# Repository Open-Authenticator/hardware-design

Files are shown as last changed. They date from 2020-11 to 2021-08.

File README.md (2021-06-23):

# Open Authenticator Hardware Design

This repository contains hardware design files and datasheets for the open authenticator. This project is in development and is not ready for release.



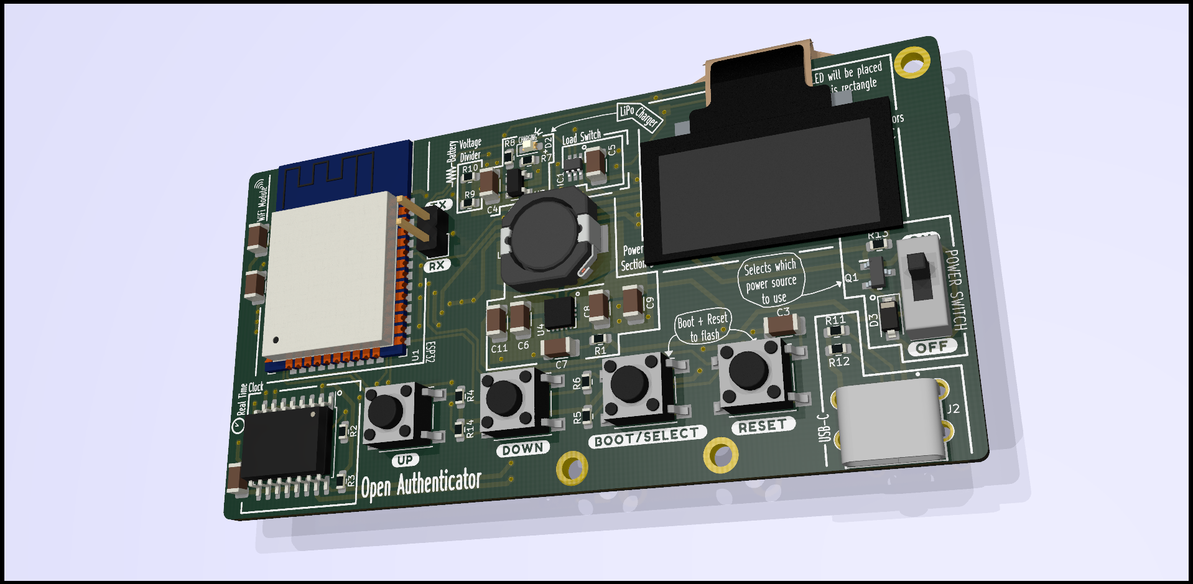
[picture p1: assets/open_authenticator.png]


## Features

* Small form factor of 82mm x 42mm
* Uses ESP32-WROOM-32D module
* Uses 128x64 0.96" inch OLED panel
* Uses DS3231 RTC with battery backup (CR2032) for timekeeping
* Powered by 3.7V 300 mAh LiPo battery
* Uses MCP73831 for charging LiPo battery
* Uses TPS63001 Buck Boost Converter IC for efficient 3.3V power supply, with input range from 1.8V - 5.5V
* Uses TPS22919 Load switch to control power to OLED and RTC chip
* Autoselect power source, i.e., battery or USB
* USB Type-C for charging only (no data pins connected)

## Project Structure

```
/datasheets - contains datasheets of various components used in the pcb
/kicad_project - contains kicad project files for the pcb
/schematics - contains schematics of the the pcb
```

## Tools

To view/modify the files from this repository, install KiCAD from: [https://kicad.org](https://kicad.org)

## Schematics



## Plots

### Front side

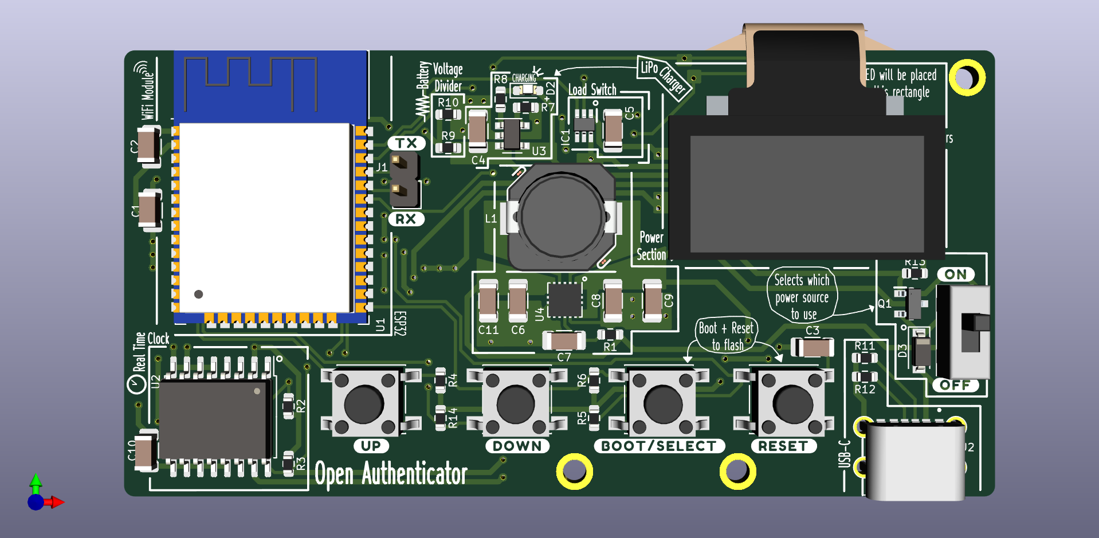
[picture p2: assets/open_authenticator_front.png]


### Back side

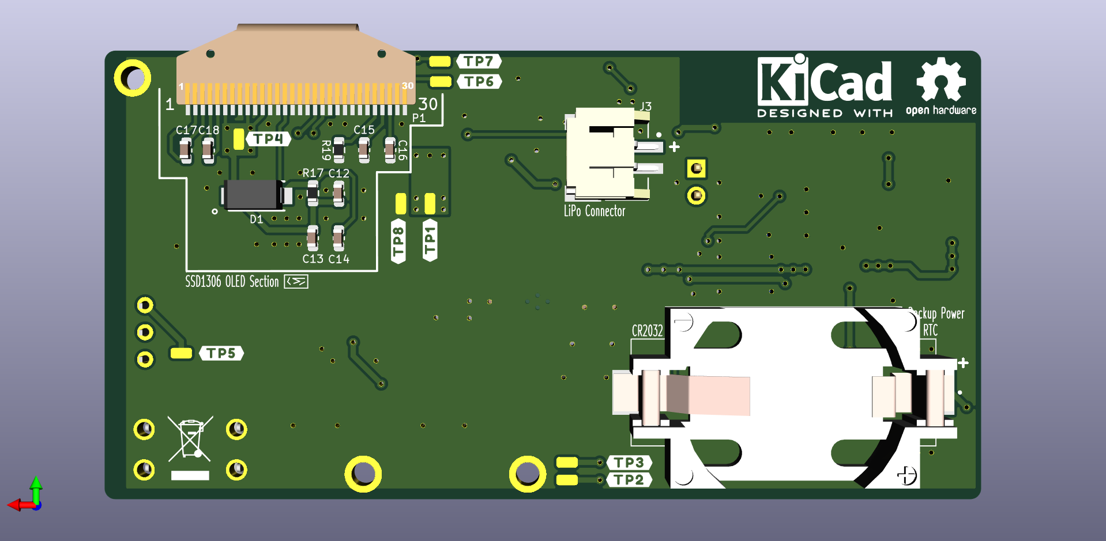
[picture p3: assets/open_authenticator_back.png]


## Credits



Thanks to OSHPark for sponsoring first prototypes



Thanks to PCBway for sponsoring the final prototypes

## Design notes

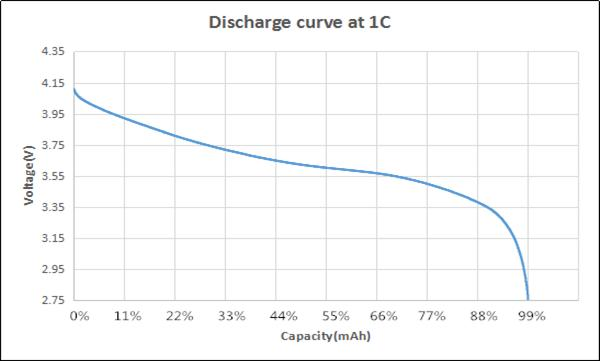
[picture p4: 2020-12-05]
datasheets/battery_discharge_curve.png

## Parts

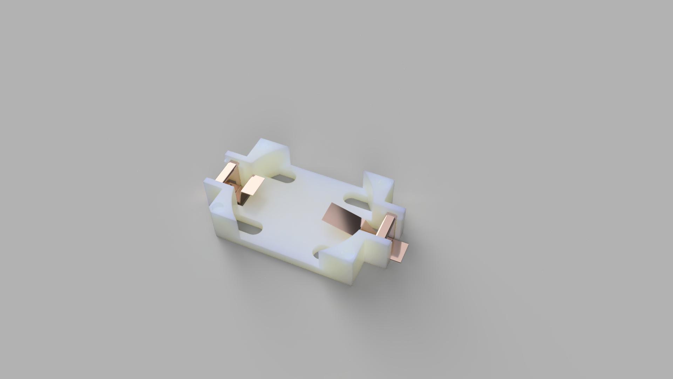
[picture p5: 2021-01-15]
kicad_project/component_libraries/2032-BS-6-1-coin-cell-holder/CR2032_holder_2018-Jul-28_07-22-14PM-000_CustomizedView1611227186.jpg

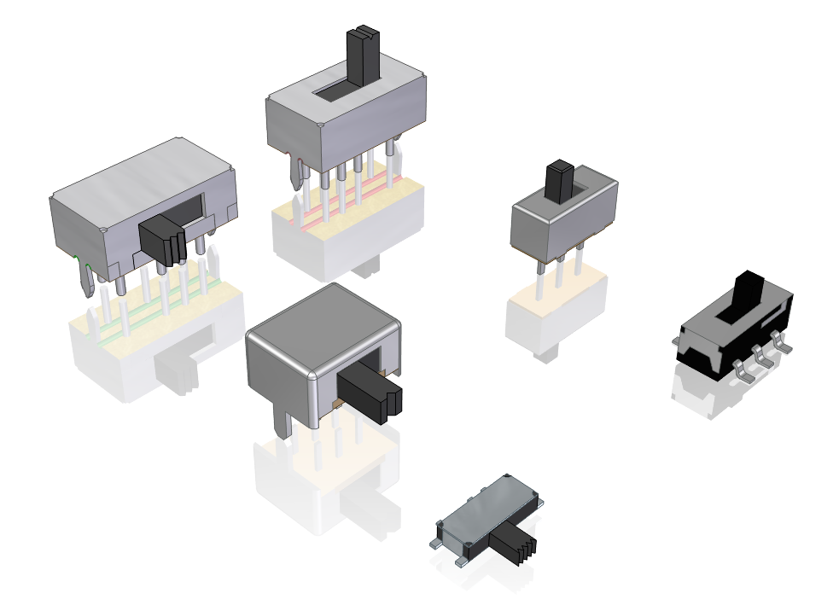
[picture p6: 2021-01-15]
kicad_project/component_libraries/SS-12D00-slide-switch/Selector Switch Assortment.PNG

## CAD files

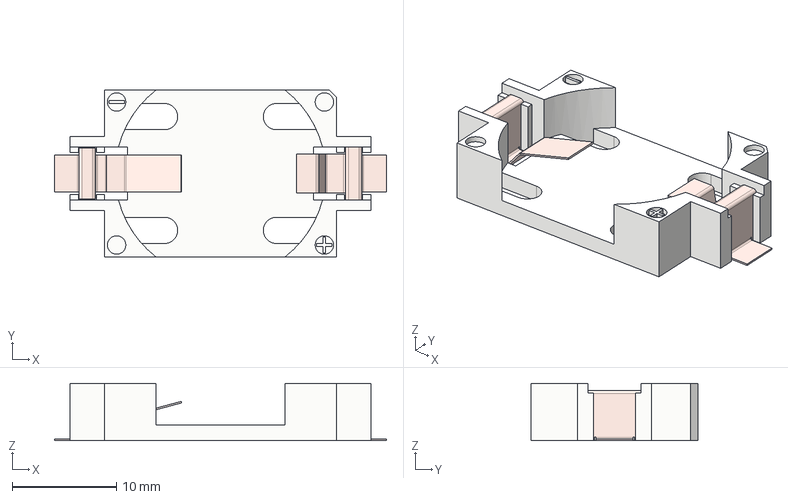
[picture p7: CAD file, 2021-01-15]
kicad_project/component_libraries/2032-BS-6-1-coin-cell-holder/CR2032 holder.step
31.8 x 16.0 x 5.50 mm
base
connector_plus
connector_minus

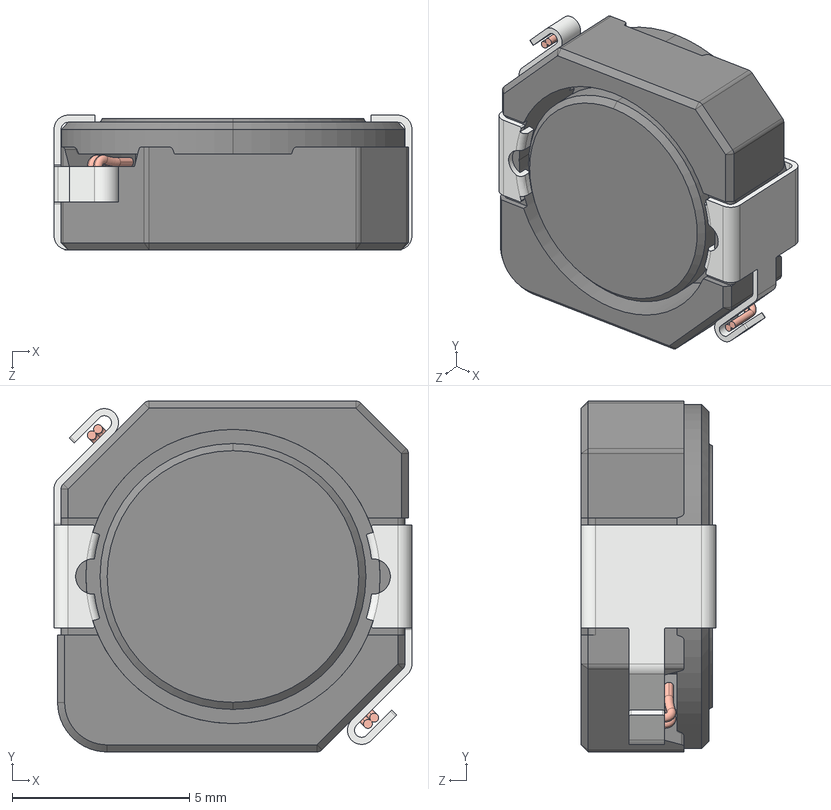
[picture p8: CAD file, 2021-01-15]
kicad_project/component_libraries/CDRH104RNP-inductor/CDRH104R.STEP
10.1 x 9.90 x 3.80 mm

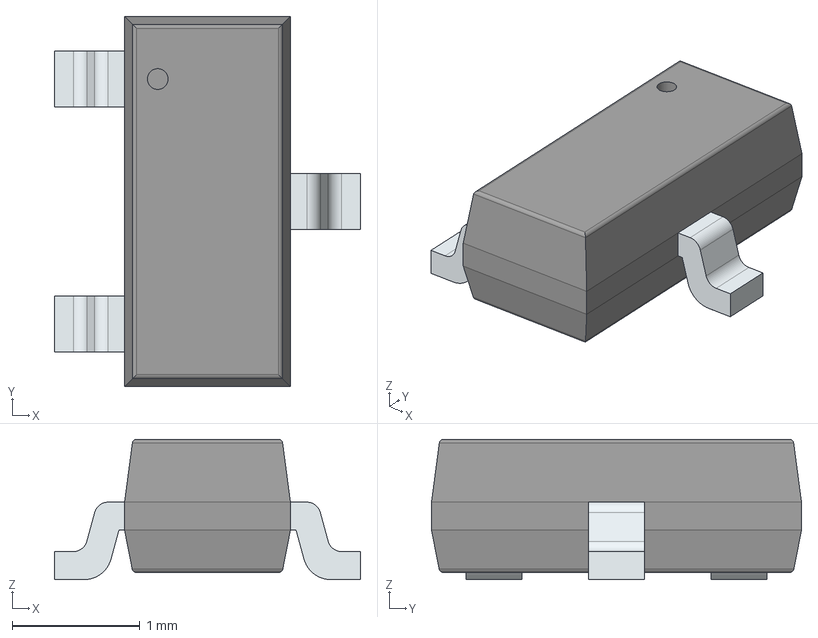
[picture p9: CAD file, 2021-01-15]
kicad_project/component_libraries/DMP2305U-mosfet/DMP2305U-7.stp
2.40 x 2.90 x 1.10 mm
PinsArrayL
FilletPinR

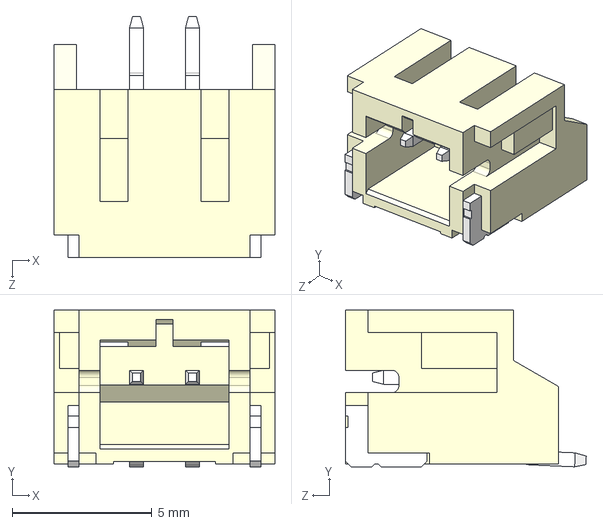
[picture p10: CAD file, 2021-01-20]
kicad_project/component_libraries/JST-PH-2pin-connector/S2B-PH-SM4-TB_LF__SN_.step
7.90 x 5.60 x 8.60 mm

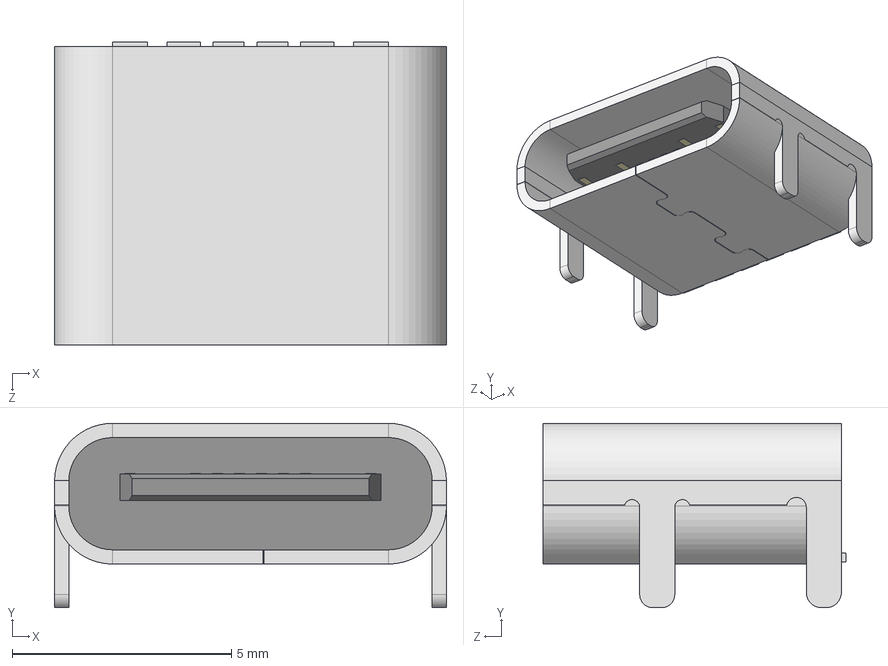
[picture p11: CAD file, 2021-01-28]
kicad_project/component_libraries/KOREAN-HROPARTS-ELEC-TYPE-C-31-M-17-usb-type-c-receptable-6-pin/TYPE-C-M-31-17.STEP
8.94 x 4.21 x 6.90 mm
HRO_TYPE-C-31-M-12
usb_C_buh

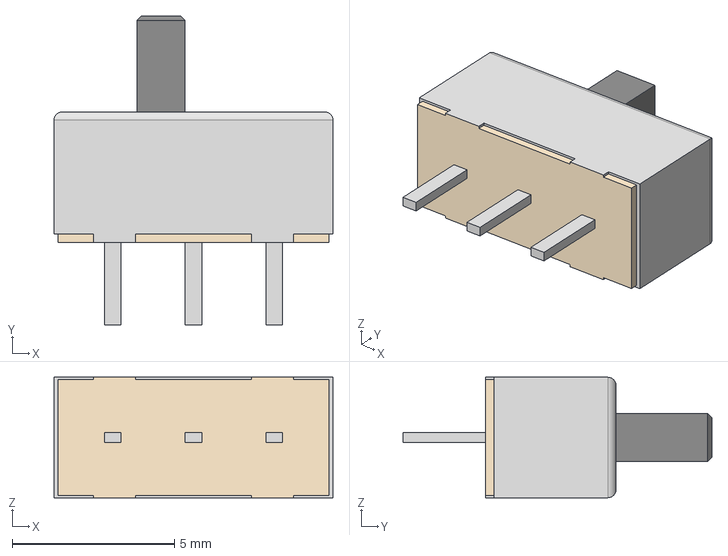
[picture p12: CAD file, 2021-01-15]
kicad_project/component_libraries/SS-12D00-slide-switch/Selector Switch - SS12D00.stp
8.59 x 9.50 x 3.71 mm

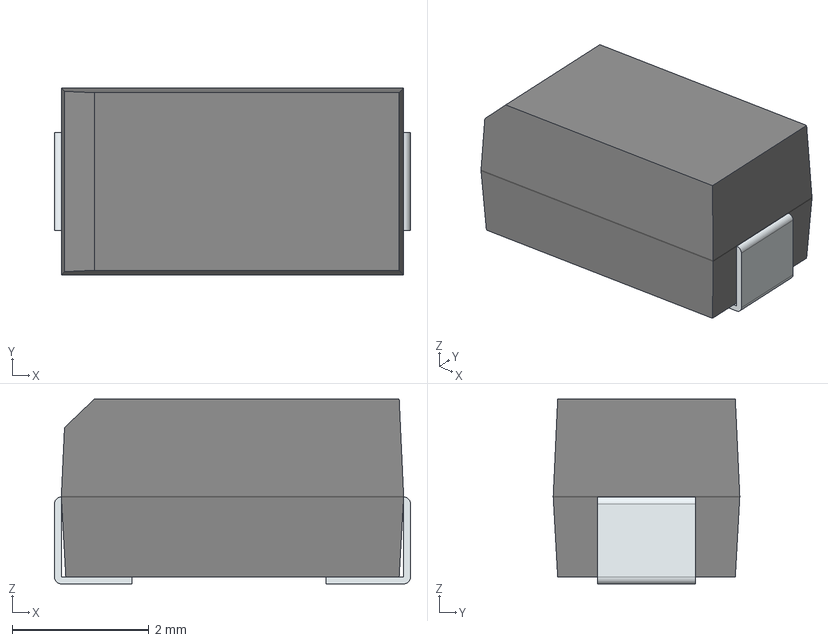
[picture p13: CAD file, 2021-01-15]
kicad_project/component_libraries/SS14/SS14.stp
5.20 x 2.73 x 2.70 mm
FilletPin1
FilletPin2

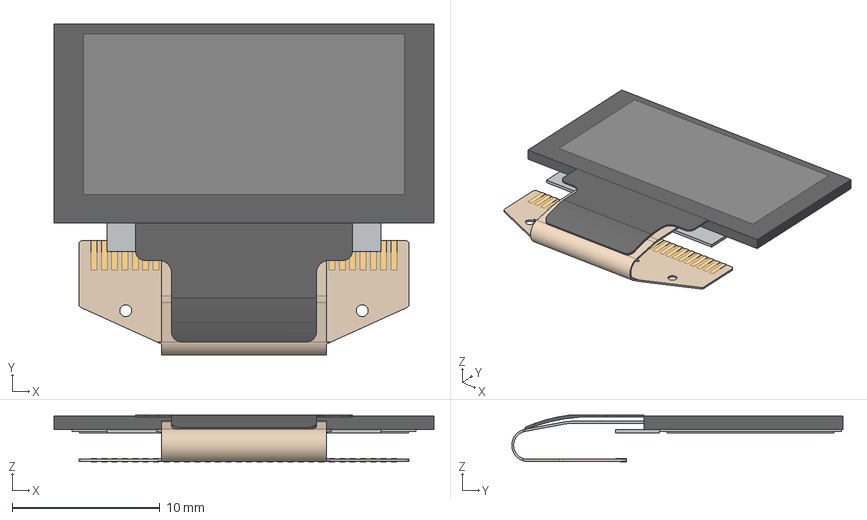
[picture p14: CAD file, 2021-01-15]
kicad_project/component_libraries/SSD1306_128x65_0.96_OLED_BARE_PANEL/0.96 OLED - Flat Reverse.stp
25.7 x 22.4 x 3.16 mm

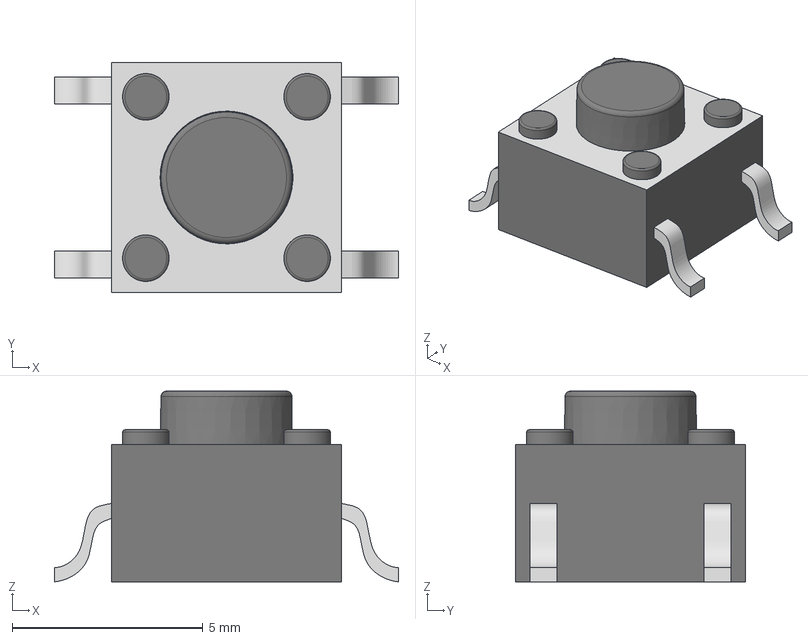
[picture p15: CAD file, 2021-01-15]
kicad_project/component_libraries/tactile_switch_3d_model/Tactal Switch - SMD (6mmx 6mmx 5mm) - Marked.stp
9.02 x 6.03 x 5.00 mm

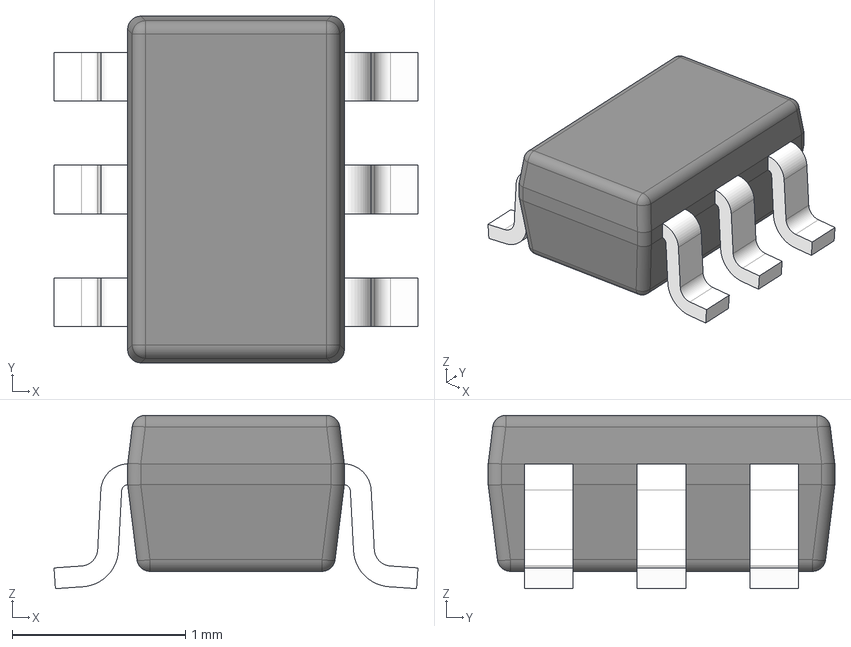
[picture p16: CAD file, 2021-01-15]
kicad_project/component_libraries/TPS22919DCKR-load-switch/DCK0006A.stp
2.10 x 2.00 x 1.00 mm
BODY-SOT
LEAD-SOT x 6
PIN1-ID

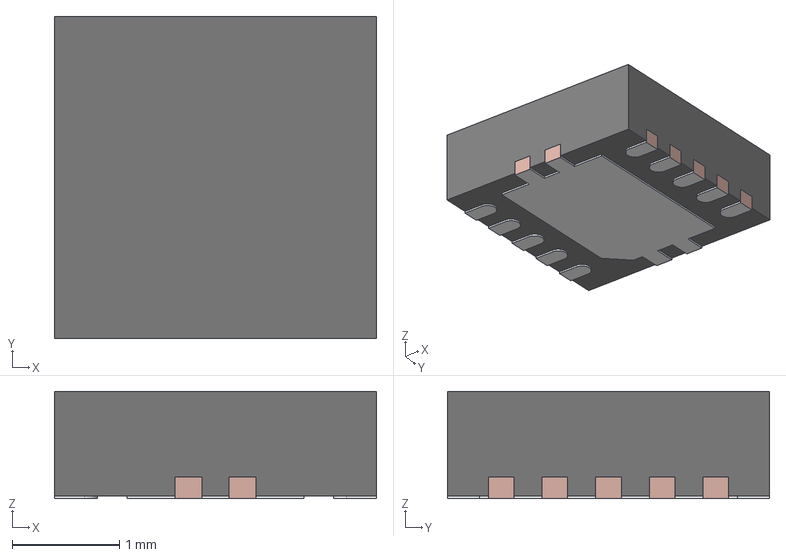
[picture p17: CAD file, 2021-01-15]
kicad_project/component_libraries/tps63001-3d-models/DRC0010J.stp
3.00 x 3.00 x 1.00 mm
BODY-SON
FRAME-DRC0010J

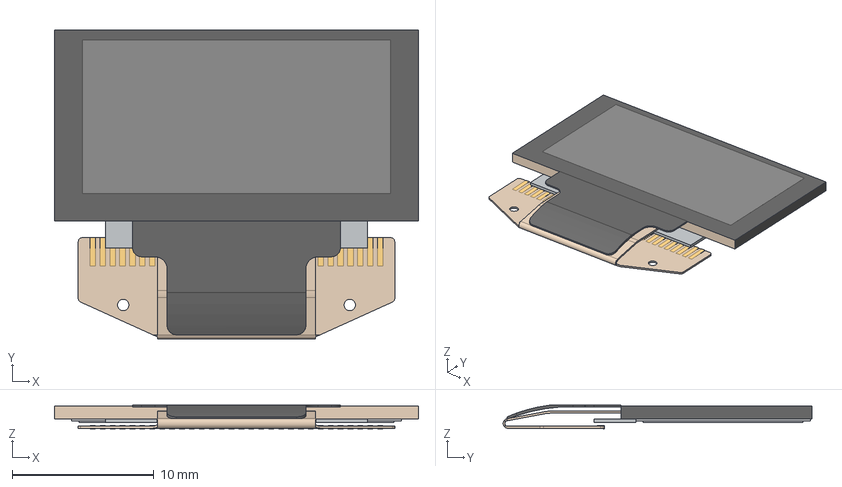
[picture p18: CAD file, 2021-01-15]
kicad_project/component_libraries/SSD1306_128x65_0.96_OLED_BARE_PANEL/0.96 OLED - Flush.stp
25.7 x 21.8 x 1.66 mm

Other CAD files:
gerber/open_authenticator-F_Paste.dxf

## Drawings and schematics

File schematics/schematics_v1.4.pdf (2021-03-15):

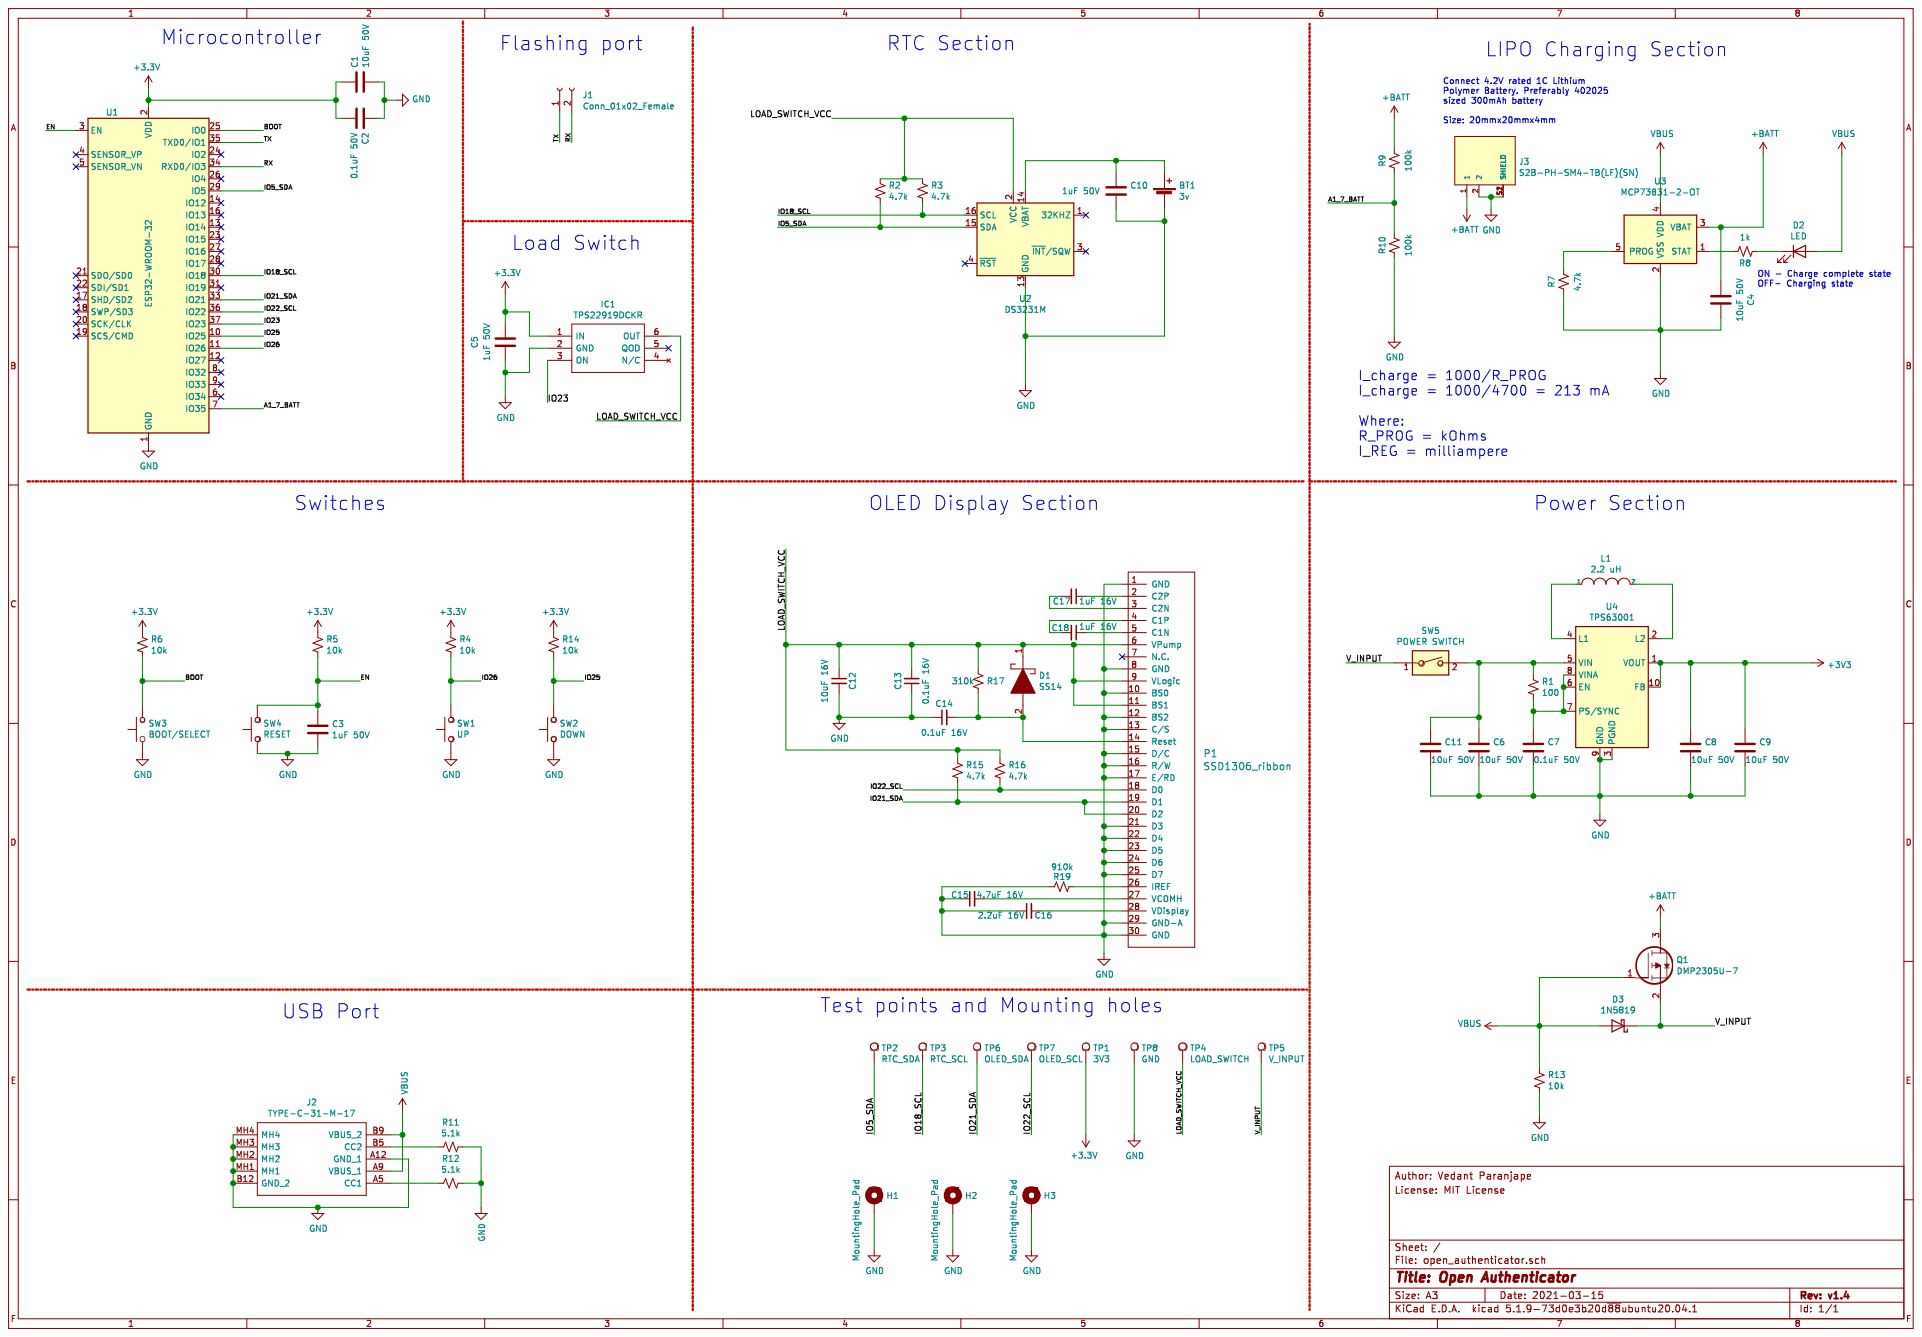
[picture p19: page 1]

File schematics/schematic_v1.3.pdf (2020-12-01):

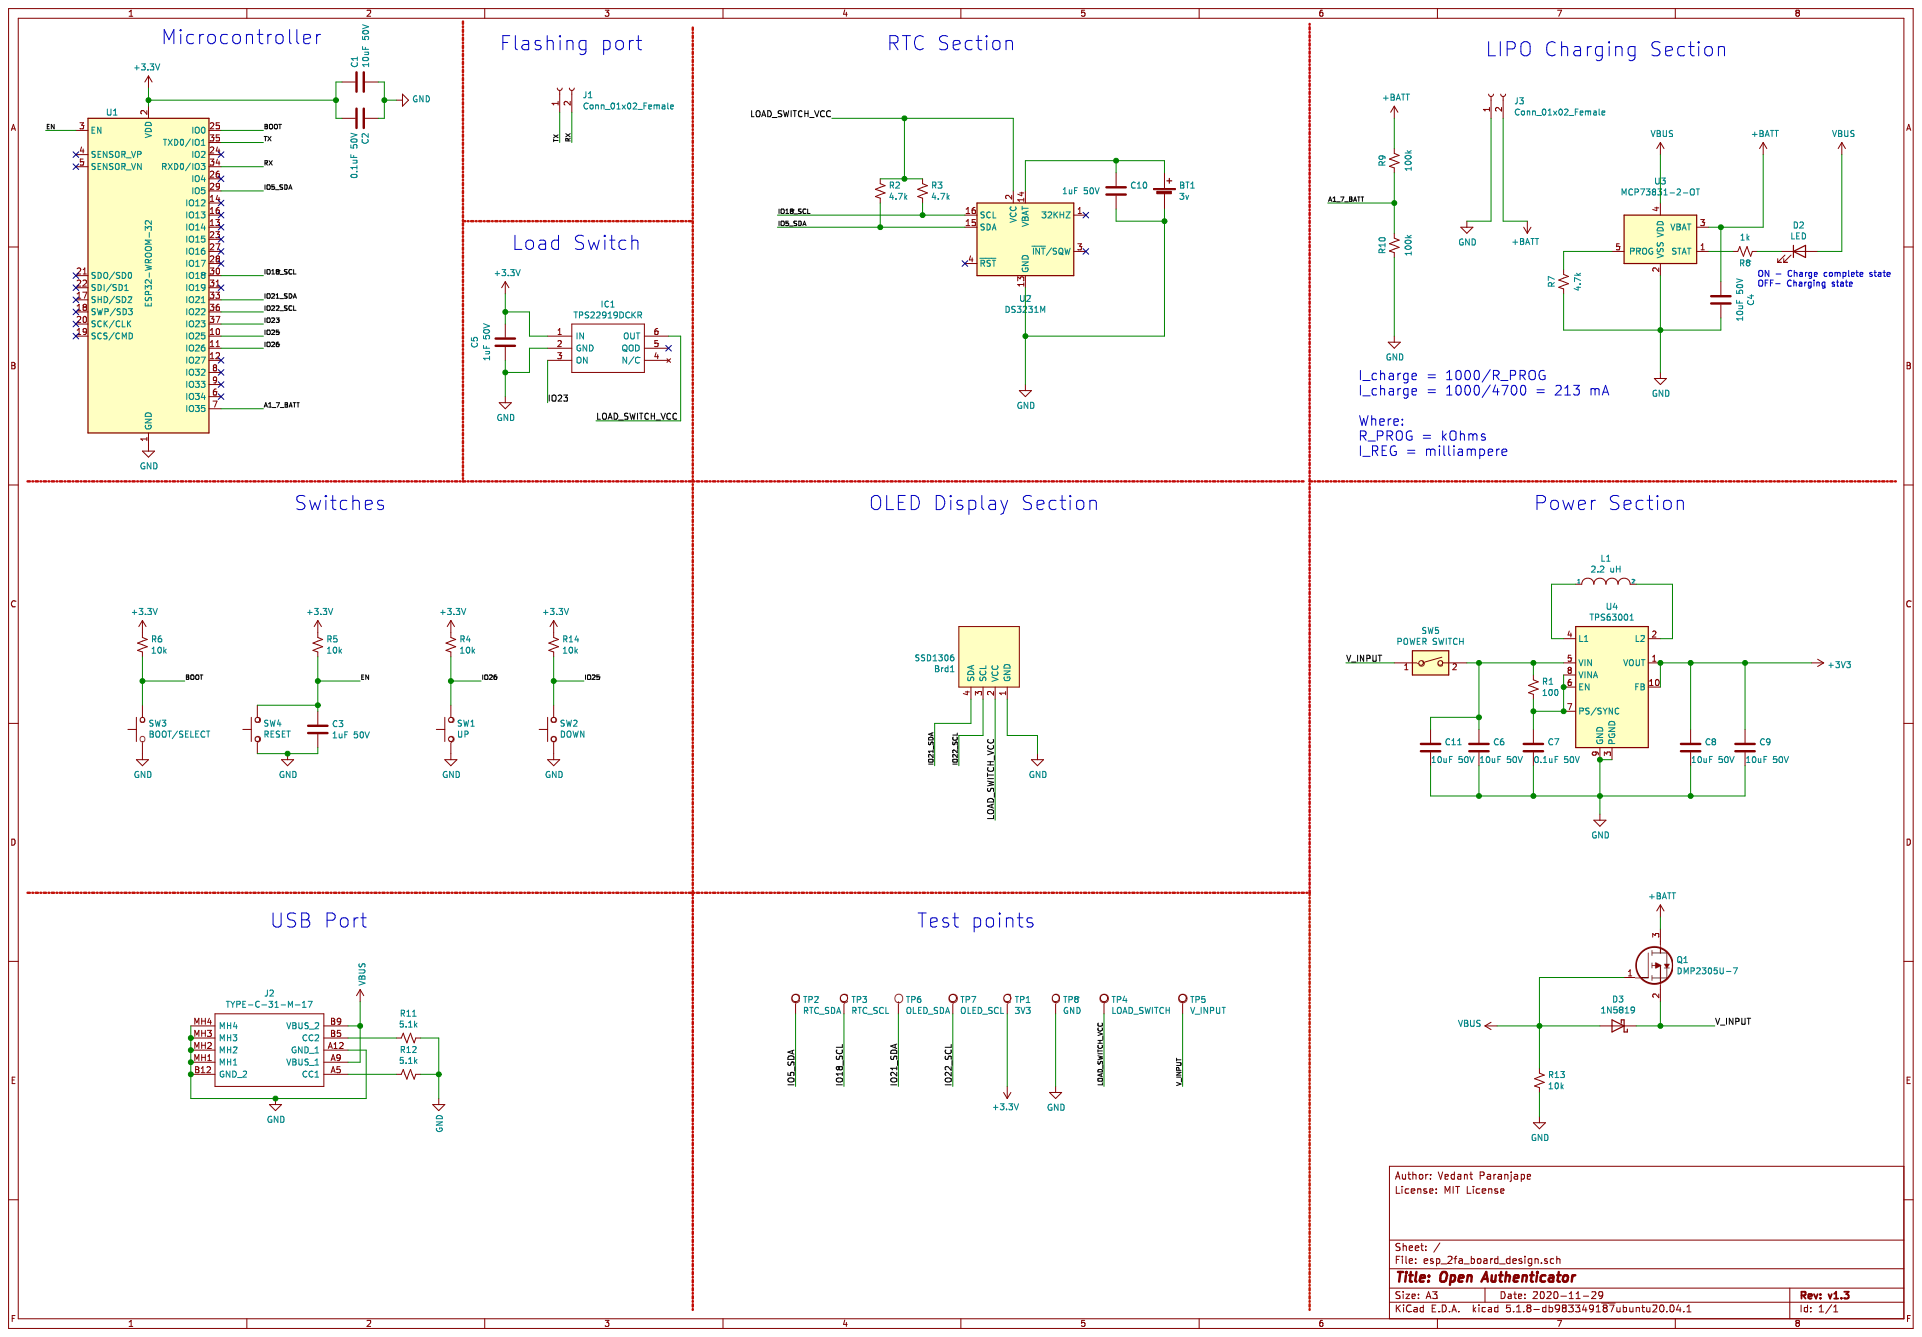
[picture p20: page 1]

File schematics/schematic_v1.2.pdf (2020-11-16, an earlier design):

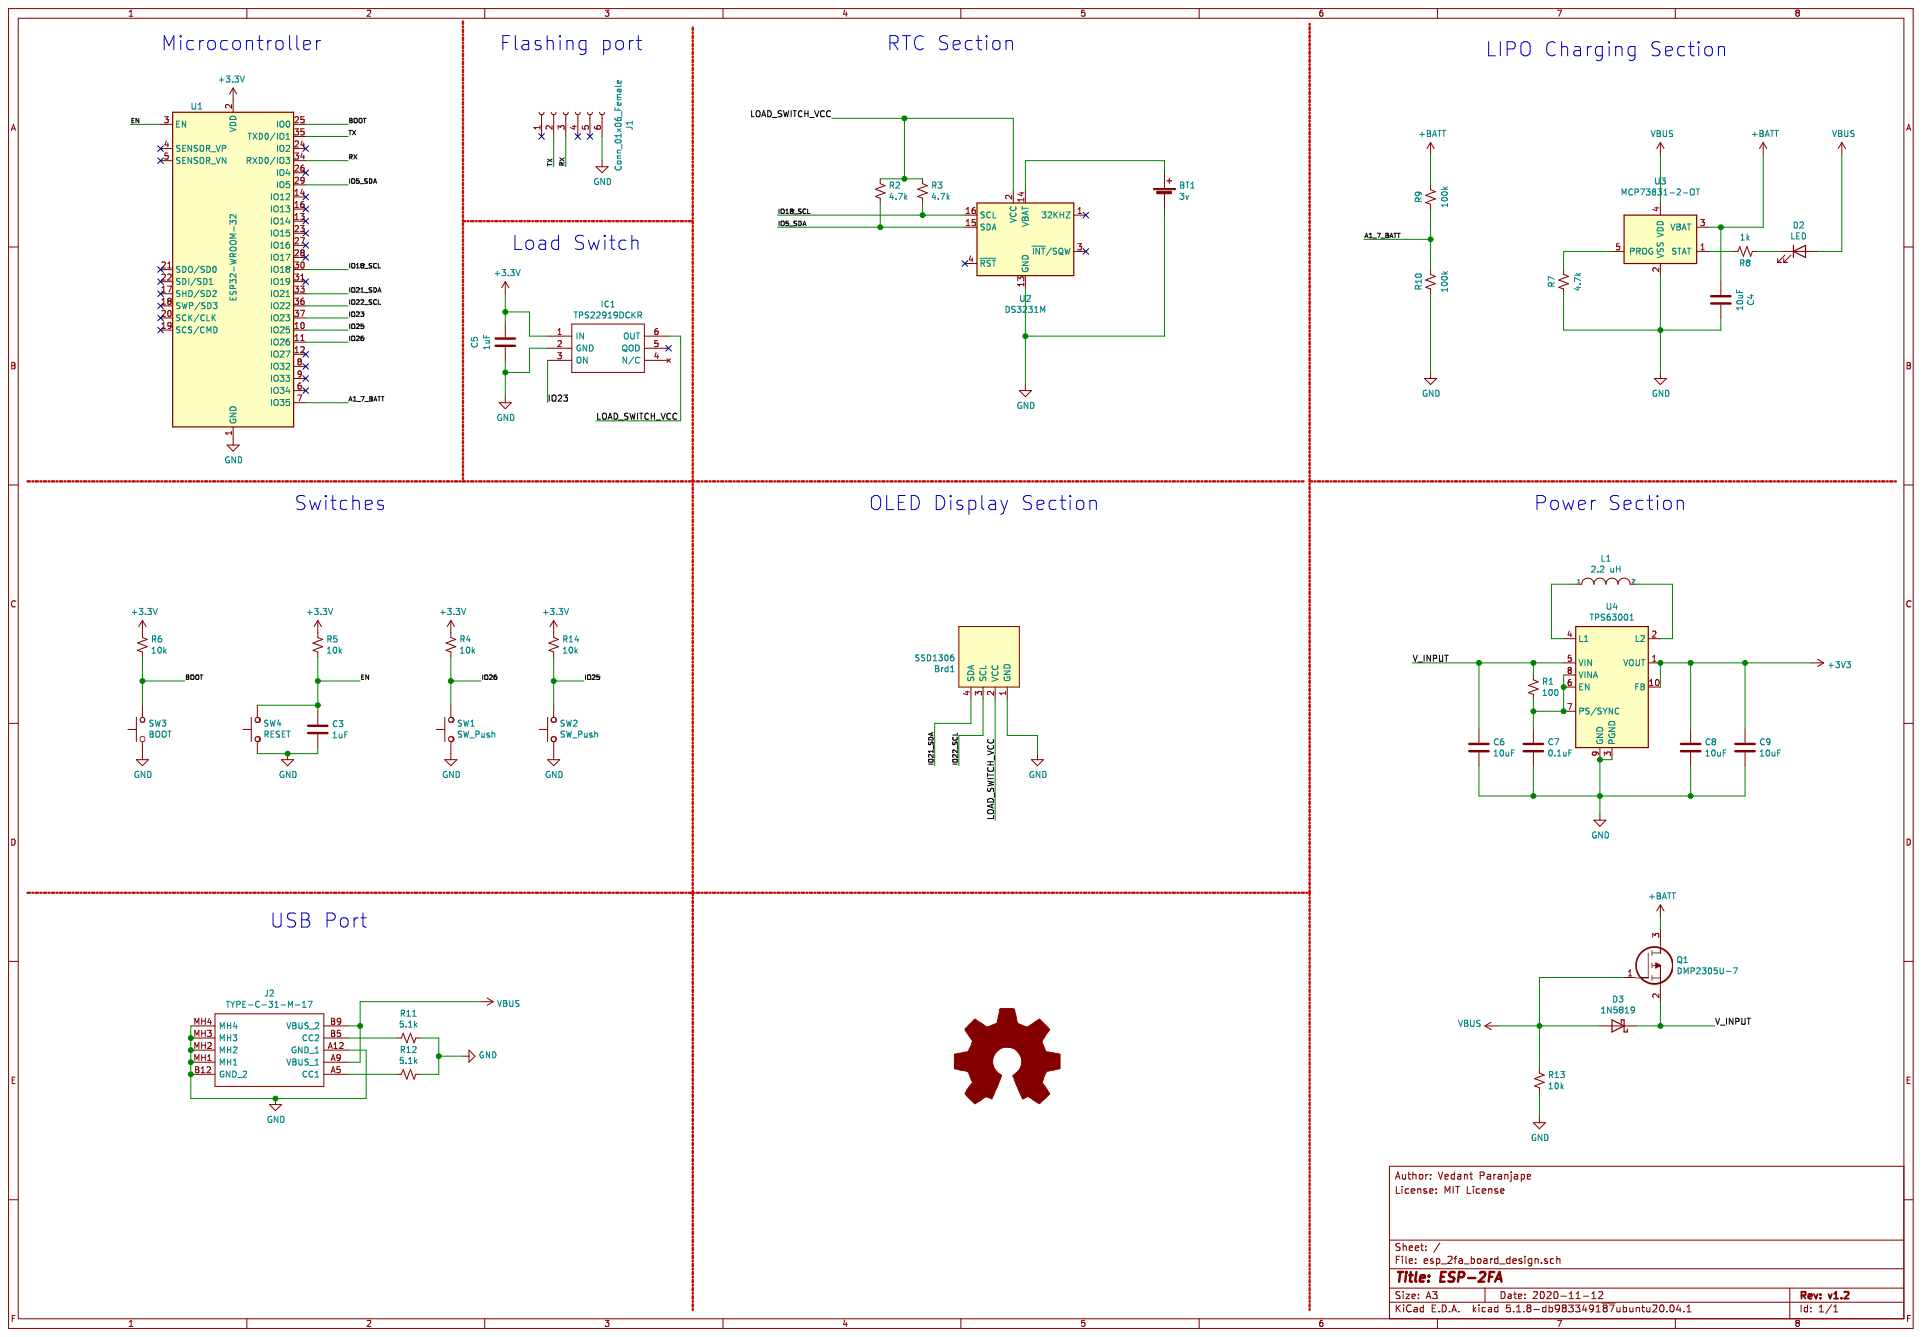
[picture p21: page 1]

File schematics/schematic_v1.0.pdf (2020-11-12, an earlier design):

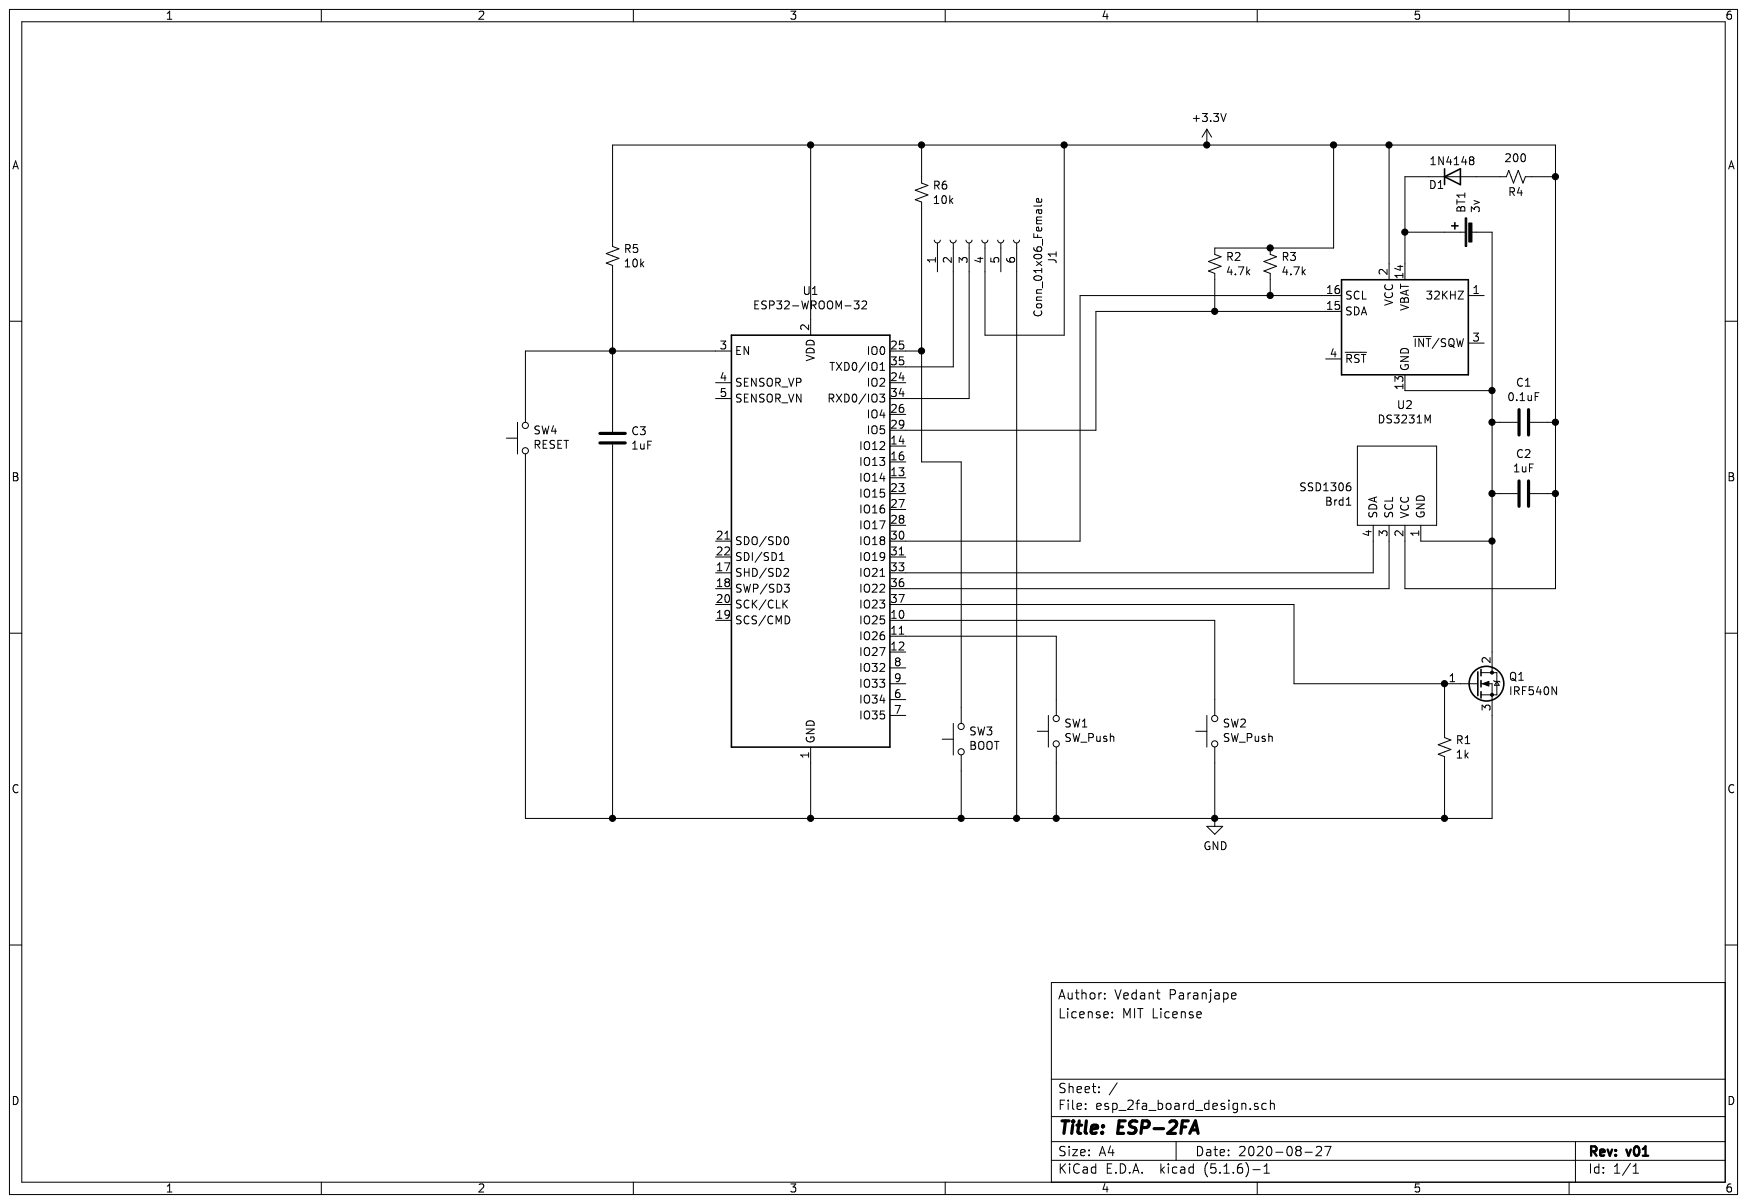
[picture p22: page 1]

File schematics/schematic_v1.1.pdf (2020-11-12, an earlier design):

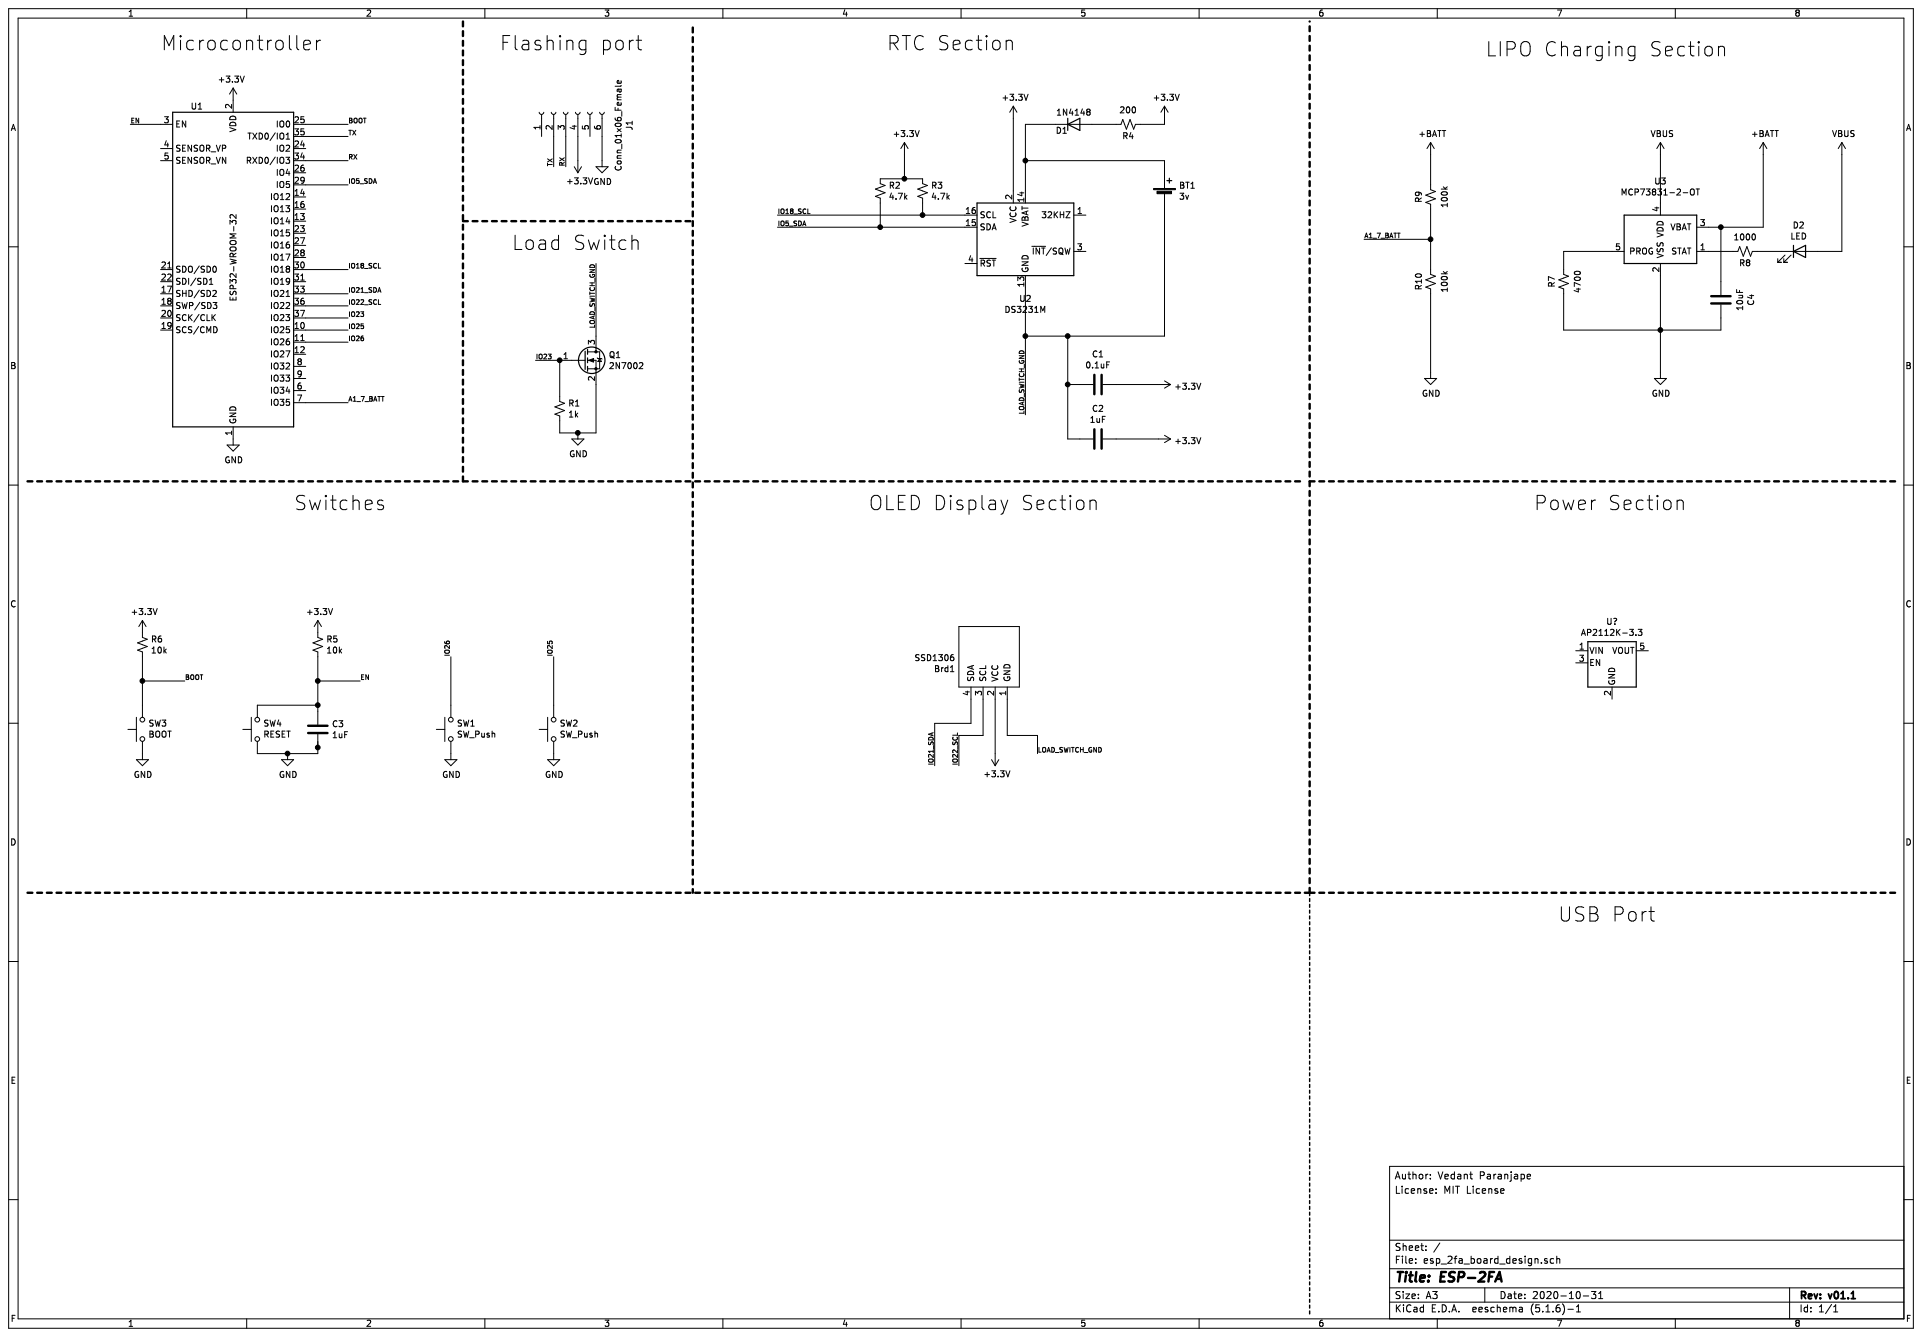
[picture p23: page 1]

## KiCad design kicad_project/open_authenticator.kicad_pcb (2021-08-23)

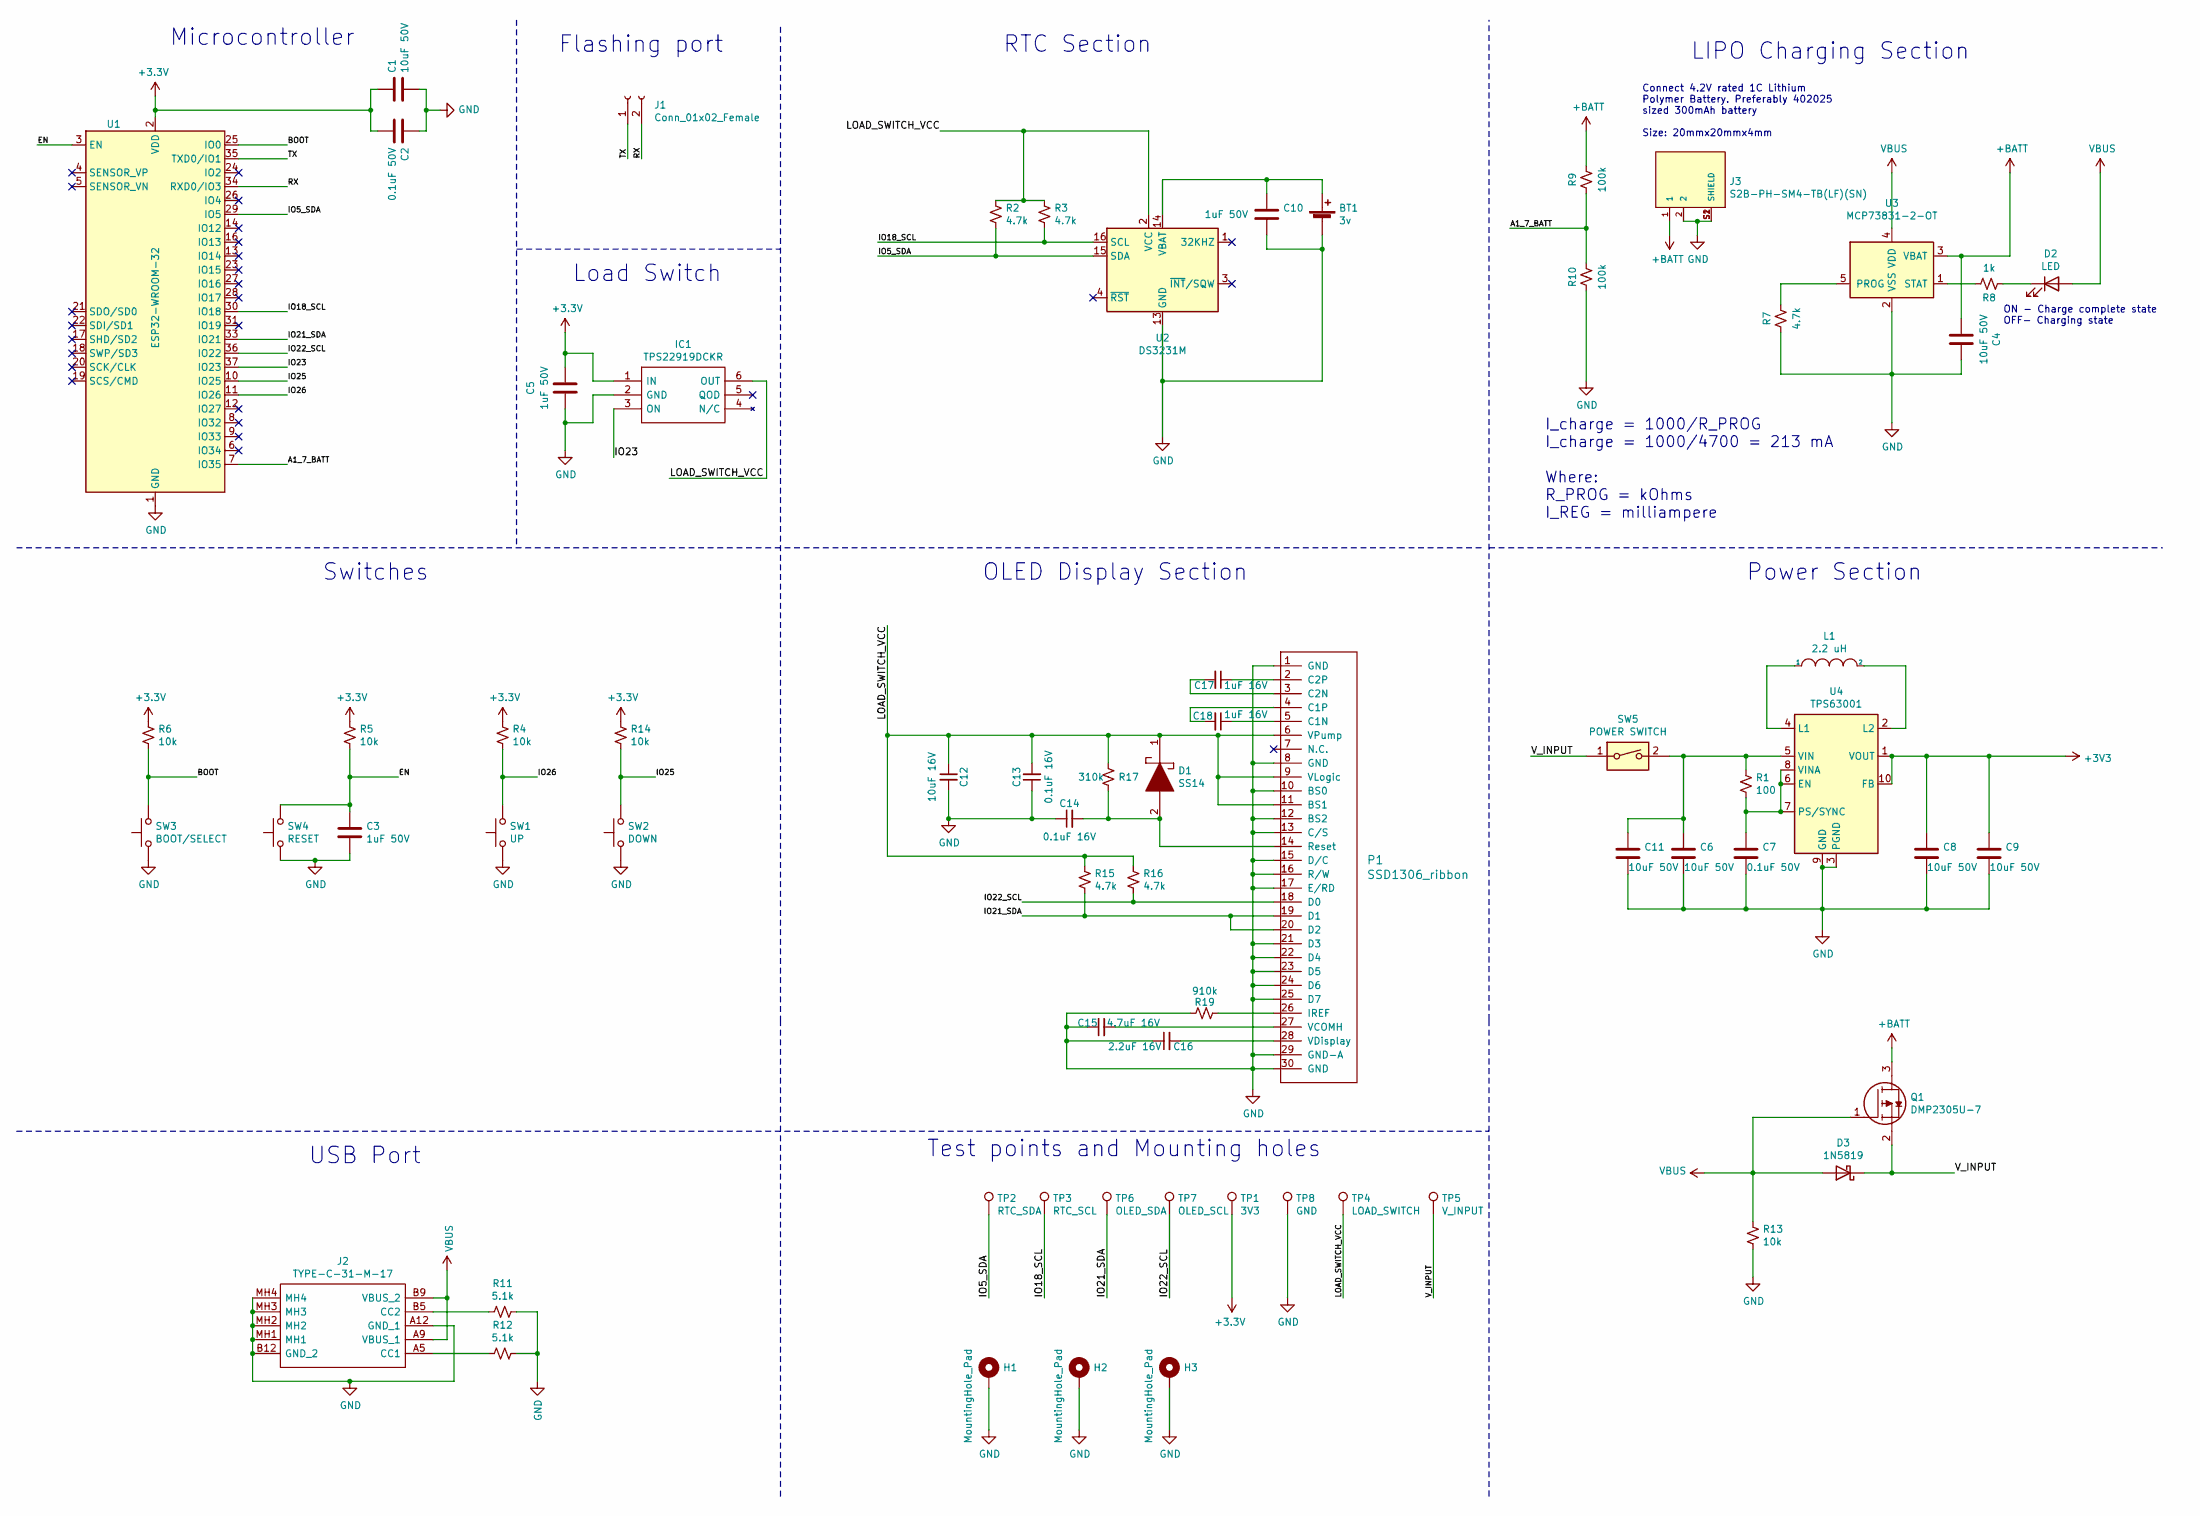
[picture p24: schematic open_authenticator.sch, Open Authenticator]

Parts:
BT1: 3v; CR2032BS61
C1, C4, C6, C8, C9, C11: 10uF 50V; C_1206_3216Metric
C2, C7: 0.1uF 50V; C_1206_3216Metric
C3, C5, C10: 1uF 50V; C_1206_3216Metric
C12: 10uF 16V; C_0603_1608Metric
C13, C14: 0.1uF 16V; C_0603_1608Metric
C15: 4.7uF 16V; C_0603_1608Metric
C16: 2.2uF 16V; C_0603_1608Metric
C17, C18: 1uF 16V; C_0603_1608Metric
D1: SS14; DIOM5227X270N; Manufacturer_Part_Number SS14; Mouser Part Number 512-SS14
D2: LED; LED_0603_1608Metric_Castellated
D3: 1N5819; D_SOD-123
H1, H2, H3: MountingHole_Pad; MountingHole_2.2mm_M2_ISO7380_Pad
IC1: TPS22919DCKR; SOT65P210X110-6N; Manufacturer_Part_Number TPS22919DCKR; Mouser Part Number 595-TPS22919DCKR
J1: Conn_01x02_Female; PinHeader_1x02_P2.54mm_Vertical
J2: TYPE-C-31-M-17; TYPEC31M17; Manufacturer_Part_Number TYPE-C-31-M-17
J3: S2B-PH-SM4-TB(LF)(SN); JST_S2B-PH-SM4-TB(LF)(SN)
L1: 2.2 uH; INDPM102100X400N
P1: SSD1306_ribbon
Q1: DMP2305U-7; SOT96P240X110-3N; Manufacturer_Part_Number DMP2305U-7; Mouser Part Number 621-DMP2305U-7
R1: 100; R_0603_1608Metric
R2, R3, R7, R15, R16: 4.7k; R_0603_1608Metric
R4, R5, R6, R13, R14: 10k; R_0603_1608Metric
R8: 1k; R_0603_1608Metric
R9, R10: 100k; R_0603_1608Metric
R11, R12: 5.1k; R_0603_1608Metric
R17: 310k; R_0603_1608Metric
R19: 910k; R_0603_1608Metric
SW1: UP; SW_Push_1P1T_NO_6x6mm_H9.5mm
SW2: DOWN; SW_Push_1P1T_NO_6x6mm_H9.5mm
SW3: BOOT/SELECT; SW_Push_1P1T_NO_6x6mm_H9.5mm
SW4: RESET; SW_Push_1P1T_NO_6x6mm_H9.5mm
SW5: POWER SWITCH; Slide_Switch_SS-12D00
TP1: 3V3; SolderWirePad_1x01_SMD_1x2mm
TP2: RTC_SDA; SolderWirePad_1x01_SMD_1x2mm
TP3: RTC_SCL; SolderWirePad_1x01_SMD_1x2mm
TP4: LOAD_SWITCH; SolderWirePad_1x01_SMD_1x2mm
TP5: V_INPUT; SolderWirePad_1x01_SMD_1x2mm
TP6: OLED_SDA; SolderWirePad_1x01_SMD_1x2mm
TP7: OLED_SCL; SolderWirePad_1x01_SMD_1x2mm
TP8: GND; SolderWirePad_1x01_SMD_1x2mm
U1: ESP32-WROOM-32
U2: DS3231M; SOIC-16W_7.5x10.3mm_P1.27mm
U3: MCP73831-2-OT; SOT-23-5
U4: TPS63001; Texas_DRC0010J_ThermalVias

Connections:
+BATT: C4.2, J3.1, Q1.3, R9.1, U3.3 (VBAT)
/A1_7_BATT: R9.2, R10.1, U1.7 (IO35)
/BOOT: R6.2, SW3.2, U1.25 (IO0)
/EN: C3.1, R5.2, SW4.2, U1.3 (EN)
/IO5_SDA: R2.2, TP2.1, U1.29 (IO5), U2.15 (SDA)
/IO18_SCL: R3.2, TP3.1, U1.30 (IO18), U2.16 (SCL)
/IO21_SDA: P1.19 (D1), P1.20 (D2), R15.2, TP6.1, U1.33 (IO21)
/IO22_SCL: P1.18 (D0), R16.2, TP7.1, U1.36 (IO22)
/IO23: IC1.3 (ON), U1.37 (IO23)
/IO25: R14.2, SW2.2, U1.10 (IO25)
/IO26: R4.2, SW1.2, U1.11 (IO26)
/LOAD_SWITCH_VCC: C12.1, C13.2, D1.1, IC1.6 (OUT), P1.6 (VPump), P1.9 (VLogic), P1.11 (BS1), R2.1, R3.1, R15.1, R16.1, R17.1, TP4.1, U2.2 (VCC)
/RX: J1.2, U1.34 (RXD0/IO3)
/TX: J1.1, U1.35 (TXD0/IO1)
/V_INPUT: D3.1 (K), Q1.2, SW5.1, TP5.1
GND: BT1.2 (-), C1.2, C2.1, C3.2, C4.1, C5.1, C6.2, C7.2, C8.2, C9.2, C10.2, C11.2, C12.2, C13.1, C14.1, C15.1, C16.1, H1.1, H2.1, H3.1, IC1.2 (GND), J2.A12 (GND_1), J2.B12 (GND_2), J2.MH1, J2.MH2, J2.MH3, J2.MH4, J3.2, J3.S1 (SHIELD), J3.S2 (SHIELD), P1.1 (GND), P1.8 (GND), P1.10 (BS0), P1.12 (BS2), P1.13 (C/S), P1.15 (D/C), P1.16 (R/W), P1.17 (E/RD), P1.21 (D3), P1.22 (D4), P1.23 (D5), P1.24 (D6), P1.25 (D7), P1.29 (GND-A), P1.30 (GND), R7.2, R10.2, R11.1, R12.1, R13.2, R19.1, SW1.1, SW2.1, SW3.1, SW4.1, TP8.1, U1.1 (GND), U1.15 (GND), U1.38 (GND), U1.39 (GND), U2.5 (GND), U2.6 (GND), U2.7 (GND), U2.8 (GND), U2.9 (GND), U2.10 (GND), U2.11 (GND), U2.12 (GND), U2.13 (GND), U3.2 (VSS), U4.3 (PGND), U4.9 (GND), U4.11 (PGND)
unnamed: BT1.1 (+), C10.1, U2.14 (VBAT)
unnamed: C7.1, R1.2, U4.6 (EN), U4.7 (PS/SYNC), U4.8 (VINA)
unnamed: C6.1, C11.1, R1.1, SW5.2, U4.5 (VIN)
unnamed: C14.2, D1.2, P1.14 (Reset), R17.2
unnamed: C15.2, P1.27 (VCOMH)
unnamed: C16.2, P1.28 (VDisplay)
unnamed: C17.1, P1.2 (C2P)
unnamed: C17.2, P1.3 (C2N)
unnamed: C18.1, P1.5 (C1N)
unnamed: C18.2, P1.4 (C1P)
unnamed: D2.1 (K), R8.2
unnamed: J2.A5 (CC1), R12.2
unnamed: J2.B5 (CC2), R11.2
unnamed: L1.1, U4.4 (L1)
unnamed: L1.2, U4.2 (L2)
unnamed: P1.26 (IREF), R19.2
unnamed: R7.1, U3.5 (PROG)
unnamed: R8.1, U3.1 (STAT)
VBUS: D2.2 (A), D3.2 (A), J2.A9 (VBUS_1), J2.B9 (VBUS_2), Q1.1, R13.1, U3.4 (VDD)

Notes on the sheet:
Microcontroller
Flashing port
RTC Section
OLED Display Section
Switches
Load Switch
LIPO Charging Section
Power Section
USB Port
Test points and Mounting holes
ON - Charge complete state OFF- Charging state
I_charge = 1000/R_PROG I_charge = 1000/4700 = 213 mA Where: R_PROG = kOhms I_REG = milliampere
Connect 4.2V rated 1C Lithium Polymer Battery. Preferably 402025 sized 300mAh battery Size: 20mmx20mmx4mm

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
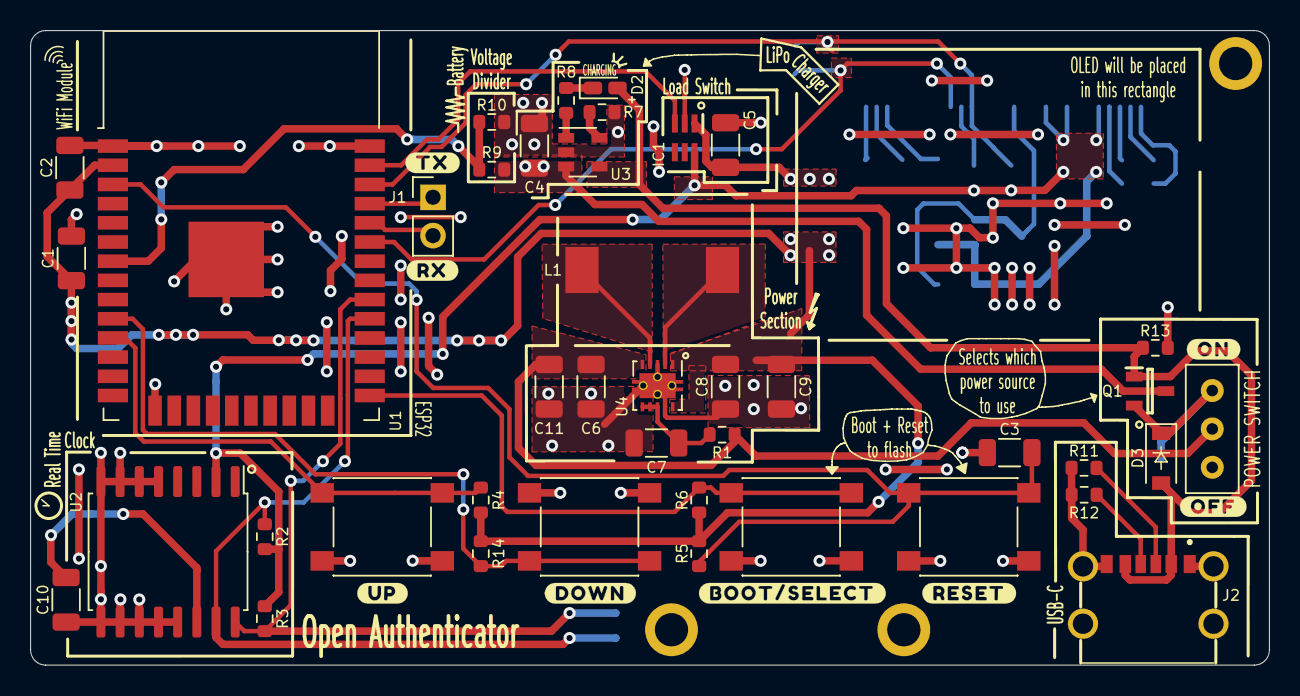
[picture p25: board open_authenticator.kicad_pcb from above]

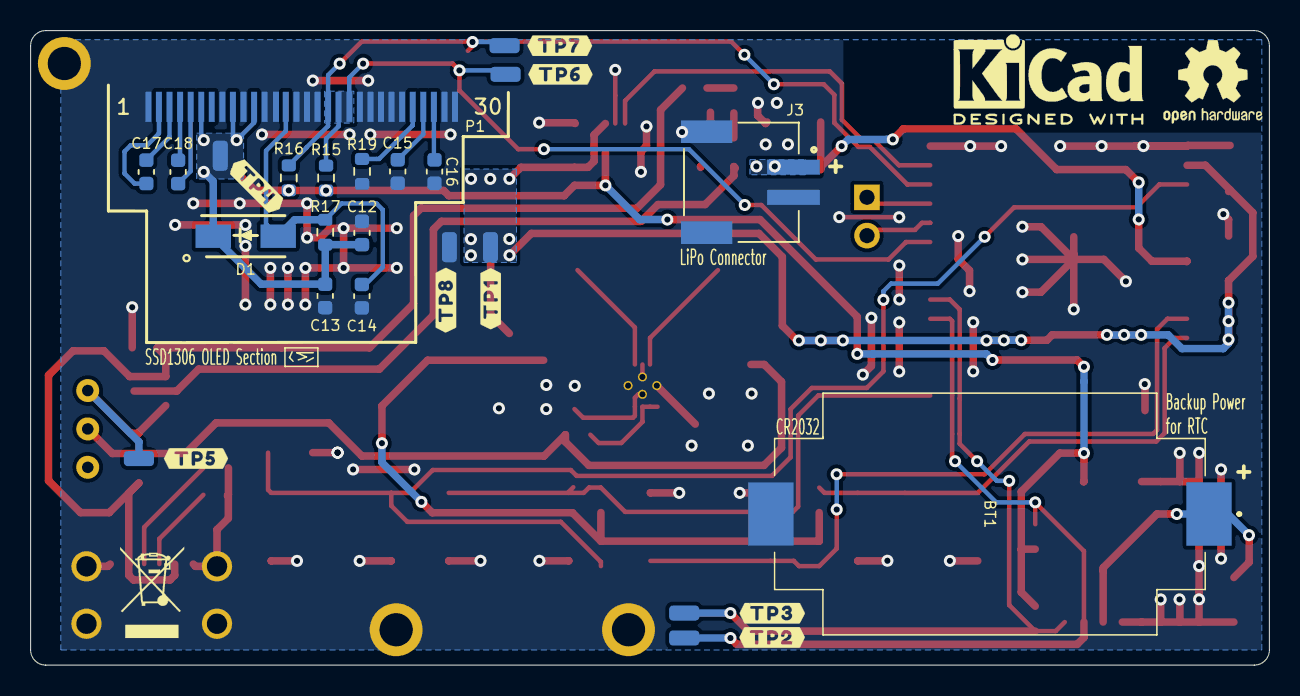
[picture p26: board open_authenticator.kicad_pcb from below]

Board: 2 copper layers, 82.0 x 42.0 mm, 67 parts (23 on the bottom side), 36 nets.

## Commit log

2020-11-12 Added hardware dessign files
    [esp_2fa_board_design.kicad_pcb, esp_2fa_board_design.sch]
2020-11-15 Updated schematics - removed coin cell charging circuit
    [esp_2fa_board_design.sch]
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2020-11-16 Completed footprint association and generated Bill of materials
    [esp_2fa_board_design.sch]
2020-11-16 Changed dmp2045u with cheaper dmp2305u and added pull resistor to switches
    [esp_2fa_board_design.sch]
2020-11-16 Started layout of components. Fixed the Edge cut of PCB and rough location of components. Routing is yet to be done
    [esp_2fa_board_design.kicad_pcb, esp_2fa_board_design.sch]
2020-11-17 Renamed auto generated bill
    [esp_2fa_board_design.csv]
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2020-11-19 Addede datasheets and partially completed routing
    [esp_2fa_board_design.kicad_pcb]
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2020-11-21 Updated schematics according review feedback
    [esp_2fa_board_design.kicad_pcb, esp_2fa_board_design.sch]
2020-11-21 Updated schematics to add lipo output current
    [esp_2fa_board_design.sch]
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2020-11-25 Partially completed routing, regulator section remains
    [esp_2fa_board_design.kicad_pcb, esp_2fa_board_design.sch]
2020-11-26 Updated pcb design to reduce routes in the ground plane
    [esp_2fa_board_design.kicad_pcb]
2020-11-26 Bridged the splits under the voltage regulator
    [esp_2fa_board_design.kicad_pcb]
2020-11-26 Minor fixes - Removed routes with 90 degree turns
    [esp_2fa_board_design.kicad_pcb]
2020-11-26 Completed pcb routing, minor touch ups and placing testpoints remaining
    [esp_2fa_board_design.kicad_pcb]
2020-11-26 Removed thermal relief from ground plane as not using any tht components
    [esp_2fa_board_design.kicad_pcb]
2020-11-27 Updated schematics by adding one more filter capacitor to voltage regulator VIN and changed routing accordingly
    [esp_2fa_board_design.kicad_pcb, esp_2fa_board_design.sch]
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2020-11-28 Changed thermal via sizes to match manufacturer specs
    [esp_2fa_board_design-B_Cu.gbr, esp_2fa_board_design-B_Mask.gbr, esp_2fa_board_design-B_Paste.gbr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]
2020-11-29 Removed test point from paste layer
    [esp_2fa_board_design-B_Cu.gbr, esp_2fa_board_design-B_Mask.gbr, esp_2fa_board_design-B_Paste.gbr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]
2020-11-30 Updated pcb to increase rx/tx header size
    [esp_2fa_board_design.kicad_pcb, esp_2fa_board_design.sch]
2020-12-01 Replaced footprint of switch with custom made
    [esp_2fa_board_design.kicad_pcb, esp_2fa_board_design.sch]
2020-12-01 Removed files excluded from gitignore
    [esp_2fa_board_design.csv]
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2020-12-01 Updated KiCad project with new path to component libraries
    [esp_2fa_board_design.kicad_pcb, esp_2fa_board_design.sch]
2020-12-01 Added plots and schematics to readme
    [esp_2fa_board_design.sch]
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2020-12-01 Minor fix to README and added raytraced rendering of board
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2020-12-05 Updated PCB and gerber, also added datasheet of battery
    [open_authenticator-B_Cu.gbr, open_authenticator-B_Mask.gbr, open_authenticator-B_Paste.gbr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]
2021-01-12 Updated placement of certain components and pads
    [open_authenticator.kicad_pcb]
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2021-01-15 Added 3D-models of majority components and added schematics of bare oled-panel, assigned footprints, routing is to be done
    [CDRH104R.STEP, CR2032 holder.step, DCK0006A.stp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]
2021-01-15 Moved oled step model to right place
    [SS14.stp, oled_128x64.STEP, open_authenticator.kicad_pcb]
2021-01-15 Added 3d model for oled, and rerouted to reduce jumpovers and optimize current path
    [0.96 OLED - Flat Reverse.stp, 0.96 OLED - Flush.stp, oled_128x64.STEP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]
2021-01-15 Optimized routing further, used copper fill zones to change plane for routes with power
    [open_authenticator.kicad_pcb]
2021-01-15 Fixed silkscreen issues
    [open_authenticator.kicad_pcb]
2021-01-15 Assigned OLED 3d model to it's footprint and moved USB-C port towards the edge
    [open_authenticator.kicad_pcb]
2021-01-15 Changed footprints of capacitors used in OLED sub circuit
    [open_authenticator.sch]
2021-01-15 [WIP] Started routing components used for OLED sub circuit
    [open_authenticator.kicad_pcb]
2021-01-16 Routed components of OLED sub circuit, optimised routing further (major: removed 3v3 line going under the regulator
    [open_authenticator.kicad_pcb]
2021-01-16 Optimised routing near slide switch
    [open_authenticator.kicad_pcb]
2021-01-16 Minor fix to routing and added artistic silkscreen drawings
    [open_authenticator.kicad_pcb]
2021-01-18 Updated silkscreen with symbols, and a bit of art
    [open_authenticator.kicad_pcb]
2021-01-18 Completed work on F.Cu Layer and F.Silk
    [open_authenticator.kicad_pcb]
2021-01-18 Added mounting holes in schematics
    [open_authenticator.sch]
2021-01-18 Placed mounting holes on the board
    [open_authenticator.kicad_pcb, open_authenticator.sch]
2021-01-18 Finished cleaning up bottom layer, silkscreen also updated
    [open_authenticator.kicad_pcb]
2021-01-19 Added lipo battery connector to schematics
    [open_authenticator.sch]
2021-01-20 Added lipo connector to board and placed it accordingly
    [S2B-PH-SM4-TB_LF__SN_.step, open_authenticator.kicad_pcb]
2021-01-20 Updated schematics to include info about battery
    [open_authenticator.sch]
2021-01-20 Moved oled subcircuit so as to better fit the OLED on board
    [open_authenticator.kicad_pcb]
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2021-01-22 Updated silkscreen to include bounds of the OLED
    [open_authenticator.kicad_pcb]
2021-01-28 Fixed DRC warnings
    [open_authenticator.kicad_pcb]
2021-01-28 Minor changes to pcb and gerber files added
    [open_authenticator-B_Cu.gbl, open_authenticator-B_Cu.gbr, open_authenticator-B_Mask.gbr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]
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2021-03-15 Changed R17 from 4.7k -> 310k in schematics to fix OLED Reset Issue
    [open_authenticator.sch]
2021-03-15 Updated value of R17 in routing and regenerated schematics
    [open_authenticator.kicad_pcb, open_authenticator.sch]
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

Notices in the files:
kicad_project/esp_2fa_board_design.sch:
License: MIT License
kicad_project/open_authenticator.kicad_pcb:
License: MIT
